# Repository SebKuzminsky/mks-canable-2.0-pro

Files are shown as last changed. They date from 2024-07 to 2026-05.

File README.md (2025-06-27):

# Information about the MKS CANable 2.0 PRO

This is a compact and inexpensive isolated USB-to-CAN
adapter that supports CAN-FD and runs well with the
[candleLight](https://github.com/candle-usb/candleLight_fw) firmware.
With candleLight, it's plug-and-play with the Linux socketcan
infrastructure.

<https://github.com/makerbase-mks/CANable-MKS>

<https://makerbase3d.com/product/makerbase-canable-v2/>

Note: The "CANable 2.0 PRO" has isolation between the CAN and the USB,
the "CANable 2.0" (non-PRO) has no isolation.  This repo focuses on the
isolated PRO version.

# Firmware update

The device ships with
[firmware](https://github.com/normaldotcom/canable2-fw) suitable for
use with [slcand](https://github.com/linux-can/can-utils/).

## One-time setup - compile the firmware

Do this once, then keep the firmware image around to flash as many
devices as you want.

1. Clone the firmware source repo: `git clone https://github.com/pgreenland/candleLight_fw.git`

2. `cd candleLight_fw`

3. Check out the `multichannel` branch (there is a
[PR](https://github.com/candle-usb/candleLight_fw/pull/176) to merge
this into mainline but it hasn't landed yet): `git checkout multichannel`

4. Install the build dependencies: `sudo apt install gcc-arm-none-eabi dfu-util cmake`

5. Build the firmware:
```
mkdir build
cd build
cmake .. -DCMAKE_TOOLCHAIN_FILE=../cmake/gcc-arm-none-eabi-8-2019-q3-update.cmake
make CANable2_MKS_fw
```

If that all works, you never have to do it again.

## Flash the device

1. Unplug from USB, install a jumper at BOOT, plug back in to USB.
Run `lsusb`, it should show up like this:
```
  Bus 001 Device 101: ID 0483:df11 STMicroelectronics STM Device in DFU Mode
```

2. Flash the firmware.  Make sure you're in the `candleLight_fw/build`
directory where you originally built the firmware image above, then run:
`make flash-CANable2_MKS_fw`.  This may print an error, `dfu-util:
can't detach`, but that's ok (see below).

3. Unplug from USB, remove BOOT jumper, re-connect USB.  `lsusb` should
show this:
```
  Bus 001 Device 102: ID 1d50:606f OpenMoko, Inc. Geschwister Schneider CAN adapter
```

At this point you can inspect and configure the CAN interface using the normal tools:

```
$ ip link show can0
20: can0: <NOARP,ECHO> mtu 16 qdisc noop state DOWN mode DEFAULT group default qlen 10 link/can
$ sudo ip link set can0 type can bitrate 500000
$ sudo ip link set can0 up
$ candump can0
  can0  401   [8]  03 00 89 3E 4C 26 38 47
  can0  440   [8]  00 18 70 39 01 26 38 47
  can0  441   [8]  E8 FF BB BD 13 26 38 47
  can0  400   [8]  00 50 F5 B8 38 3A 38 47
  can0  401   [8]  FD FF 88 3E 4A 3A 38 47
  can0  440   [8]  00 00 B7 36 8C 39 38 47
  can0  441   [8]  E8 FF BB BD 9D 39 38 47
  can0  1A4   [2]  00 01
```

# About that flashing error...

A hardware bug on the MKS CANable 2.0 PRO causes problems when rebooting
and resetting the board too quickly.  The problem is described here:
<https://github.com/makerbase-mks/CANable-MKS/issues/6>

If you don't mind leaving the board powered down for ~2 seconds whenever
you reset it, you can ignore this issue.

If you want the board to boot into the candleLight firmware every time it
resets, no matter how short the duration of the reset, you can reprogram
the Flash Option Bytes of the STM32 using these steps:

1. Install required programs (you only have to do this on each computer
you want to be able to flash): `sudo apt install openocd netcat-openbsd`

2. Connect a Single Wire Debug (SWD) probe to the CANable2 PRO board.
I use a Segger J-Link but any should work.
```
  J-Link    | CANable
  ----------+-------
  1 (Vtref) | 3.3V
  4 (GND)   | GND
  7 (SWDIO) | SWD
  9 (SWCLK) | SWC
```
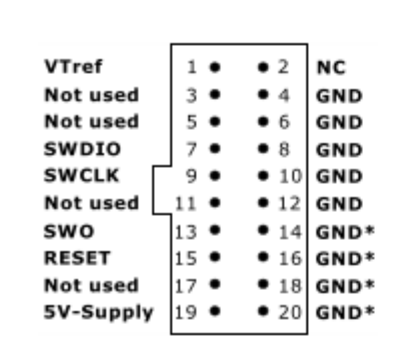
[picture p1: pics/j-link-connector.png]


3. Make sure the CANable2 and J-Link are both connected to USB.

4. Run OpenOCD (this will keep running until you stop it with
Ctrl-C): `openocd -f interface/jlink.cfg -c 'transport select swd'
-f target/stm32g4x.cfg`

5. In a different terminal, send the command list to the OpenOCD server:
`nc -N localhost 4444 < disable-boot-jumper.cfg`

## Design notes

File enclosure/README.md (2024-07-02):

Install M2.5 heat-set inserts in the four holes in the "lid" part.

Screw floor onto lid using M2.5x6 screws, preferrably Nylon on some other
non-conductive material.  Longer screws, up to 10mm or more, fit fine.

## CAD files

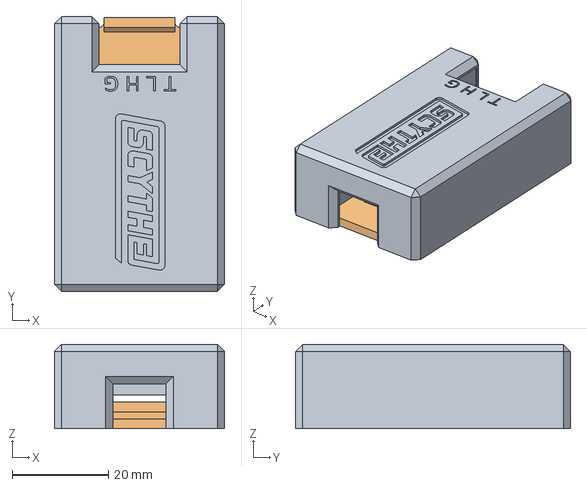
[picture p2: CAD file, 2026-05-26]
enclosure/enclosure.FCStd
35.2 x 57.0 x 17.5 mm
lid
floor

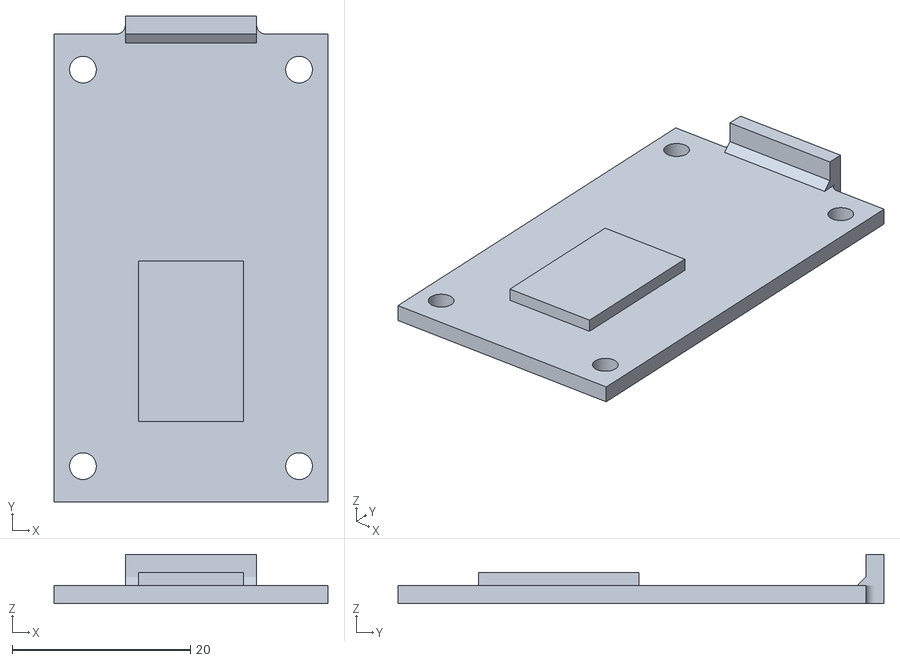
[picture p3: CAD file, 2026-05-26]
enclosure/enclosure-floor.stl
30.8 x 54.5 x 5.50

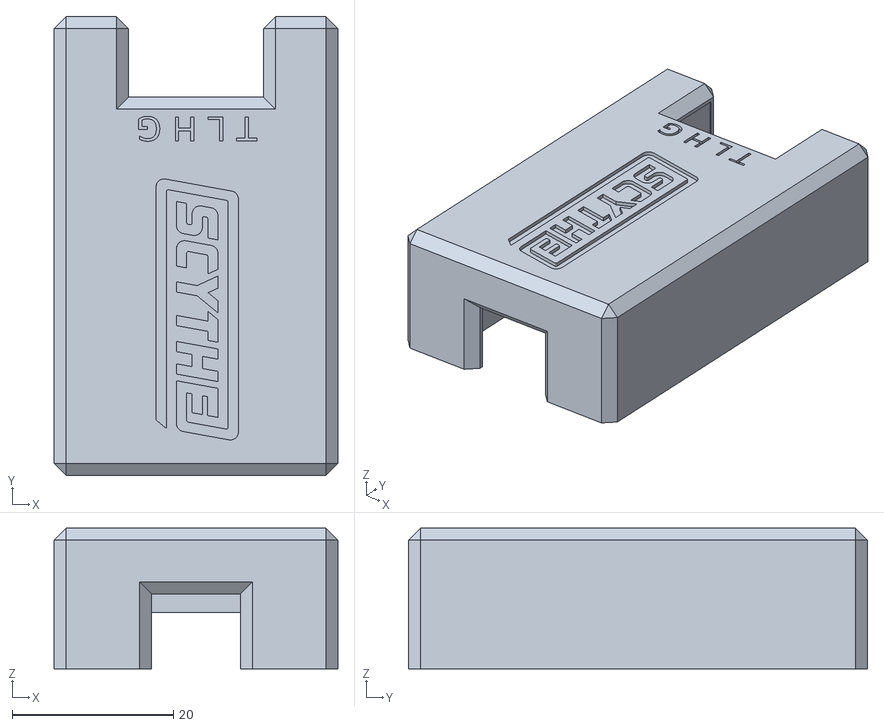
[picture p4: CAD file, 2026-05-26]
enclosure/enclosure-lid.stl
35.2 x 57.0 x 17.5

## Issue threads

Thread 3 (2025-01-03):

The Candlelight firmware does support CAN-FD.

Lockwuud, 2025-01-03:
The Candlelight firmware does support CAN-FD.

The [multichannel](https://github.com/pgreenland/candleLight_fw/tree/multichannel) branch of candleLight_fw supports CAN-FD on this device:
https://github.com/pgreenland/candleLight_fw/blob/multichannel/include/config.h#L393-L402

```
$ sudo ip link set can0 up type can bitrate 500000 dbitrate 2000000 fd on
$ sudo ip link set can1 up type can bitrate 500000 dbitrate 2000000 fd on
$ candump can0 &
[1] 3261642
$ cansend can1 '123#aabbcc'
  can0  123   [3]  AA BB CC
```

_Originally posted by @SebKuzminsky in https://github.com/SebKuzminsky/mks-canable-2.0-pro/issues/2#issuecomment-2568195341_

I have completely followed your steps to redo everything, but when I run the command `sudo ip link set can0 up type can bitrate 500000 dbitrate 2000000 fd on`, the following error occurs: `RTNETLINK answers: Operation not supported`. This seems to indicate that my device does not support CAN FD, but when I execute the command `sudo ip link set can0 up type can bitrate 500000`, it can support CAN transmission, but not CAN FD. I have also confirmed that the device I am using is the same as yours, the MKS-CANable-2.0-Pro.
It is worth noting that in your sending command `cansend can1 '123#aabbcc'`, the `#` represents a CAN frame rather than a CAN FD frame. To send a CAN FD frame, you should use `cansend can1 '123##aabbcc'`.

SebKuzminsky, 2025-01-03:
> It is worth noting that in your sending command cansend can1 '123#aabbcc', the # represents a CAN frame rather than a CAN FD frame. To send a CAN FD frame, you should use cansend can1 '123##aabbcc'.

Ah, good catch!  I'll re-try with the `##` syntax for CAN-FD frames.

But the fact that `ip set ... fd on` works for me but not for you makes me think something else has already gone wrong here.  What kernel are you running?  Which commit of `multichannel` did you flash?  What version of iproute2 is your `ip` from?  What does `lsusb` of your Canable show?

Lockwuud, 2025-01-03:
When I short the boot pin and execute `lsusb`, the recognized device is:
`Bus 003 Device 010: ID 0483:df11 STMicroelectronics STM Device in DFU Mode`.

After flashing the firmware `flash-CANable2_MKS_fw` and running `lsusb`, it shows:
`Bus 003 Device 011: ID 1d50:606f OpenMoko, Inc. CANable2-MKS gs_usb`.

I directly executed `git checkout multichannel` after pulling the repository, and the current branch is `b4dd77144e2aa2a18da7fdf246fe9de7f36b108d` (HEAD -> multichannel, origin/multichannel).

My kernel version is `5.15.0-124-generic`.

SebKuzminsky, 2025-01-03:
That all looks the same as on my machine, except the kernel version.  I'm on 6.8.0-49-generic (Ubuntu 24.04).  I have can-utils version 2023.03-1.

The CAN-FD format you pointed out for cansend does the expected thing here:
```
$ candump can0 &
$ cansend can1 '123##0.00.11.22.33.44.55.66.77.88.99.aa.bb.cc.dd.ee.ff'
can0  123  [16]  00 11 22 33 44 55 66 77 88 99 AA BB CC DD EE FF
```

Lockwuud, 2025-01-04:
It seems that the issue is indeed on my side. I will continue investigating the cause of the problem. Thank you very much for your prompt response and testing.

SebKuzminsky, 2025-01-05:
Ok!  Let me know if a newer kernel resolves your issue.  If not, please open a new issue here and we'll debug it some more.

Closed 2025-01-05.

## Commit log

2024-07-02 add a README for the enclosure
2024-07-02 automate updating of Flash Option Bytes
    [disable-boot-jumper.cfg]
2024-07-12 enclosure: expose the CAN screw terminal screws
    [enclosure-lid.stl, enclosure.FCStd]
2024-07-15 add a picture of the J-link connector pinout for reference
2025-01-27 enclosure: enlarge the cutout so the terminating jumper is accessible
    [enclosure-lid.stl, enclosure.FCStd]
2026-05-26 enclosure: add legends for screw terminal, add bottom lip
    This adds a legend, "T L H G" at the screw terminals, meaning
    "Terminator", "CAN-Low", "CAN-High", and "Ground".
    Also adds a small lip to keep the Canable board from sliding out when
    you push the USB connector in.
    [enclosure-floor.stl, enclosure-lid.stl, enclosure.FCStd]
